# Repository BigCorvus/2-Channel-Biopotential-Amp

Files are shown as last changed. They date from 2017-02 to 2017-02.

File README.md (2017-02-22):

# 2-Channel-Biopotential-Amp
A small general purpose biopotential amplifier for ECG/EEG/EMG measurements based on the TI INA2321 dual instrumentation amplifier. The device can be connected to any ADC or microcontroller with built-in ADC.

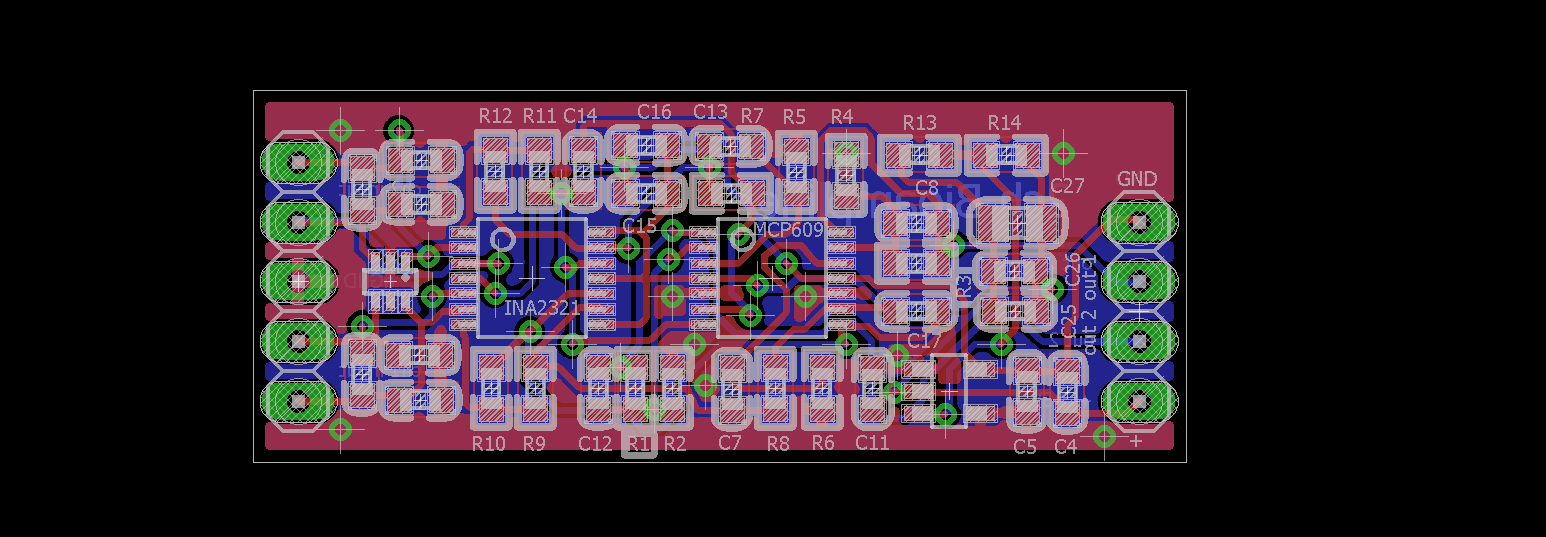
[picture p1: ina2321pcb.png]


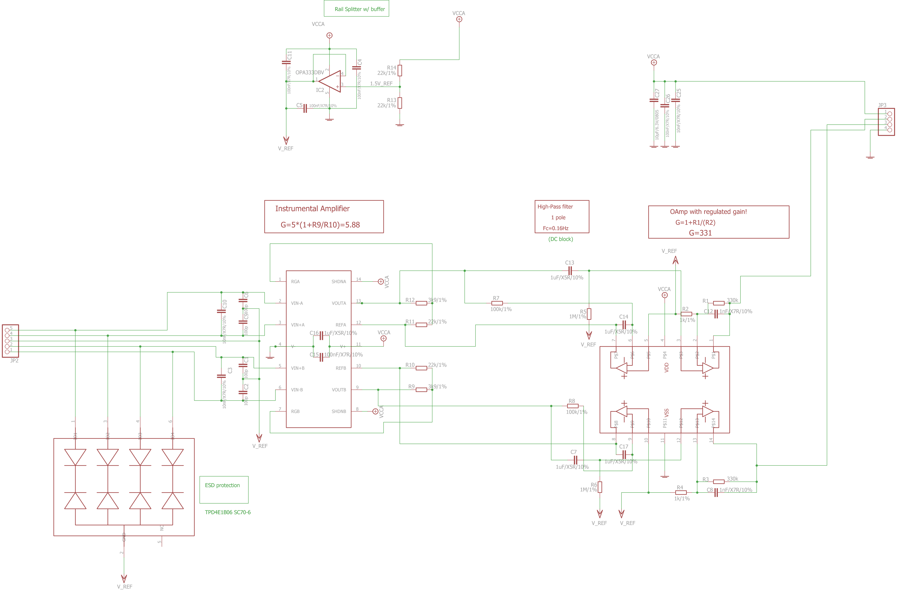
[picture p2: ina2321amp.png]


These can be stacked together to easily increase the channel count of your system.

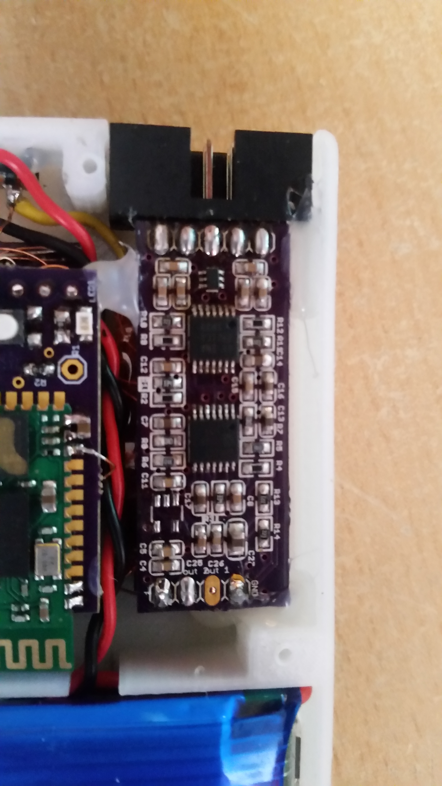
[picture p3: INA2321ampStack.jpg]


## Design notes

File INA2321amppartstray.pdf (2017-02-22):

INA2321 amp Parts Tray (passives)

Resistors – all 0603 1%:

1M: R5,6

100K: R7,8

3k9: R12,9

22k: R10,11,13,14

1k: R4,2

330k: R1,3

Caps:

4x 100p @ inputs

3x10n: @ inputs and C25

1µFx5r0603 C13,14,7,17

100n0603: C4,5,26,11,15

10µ0805: C27

1nF: C6,12

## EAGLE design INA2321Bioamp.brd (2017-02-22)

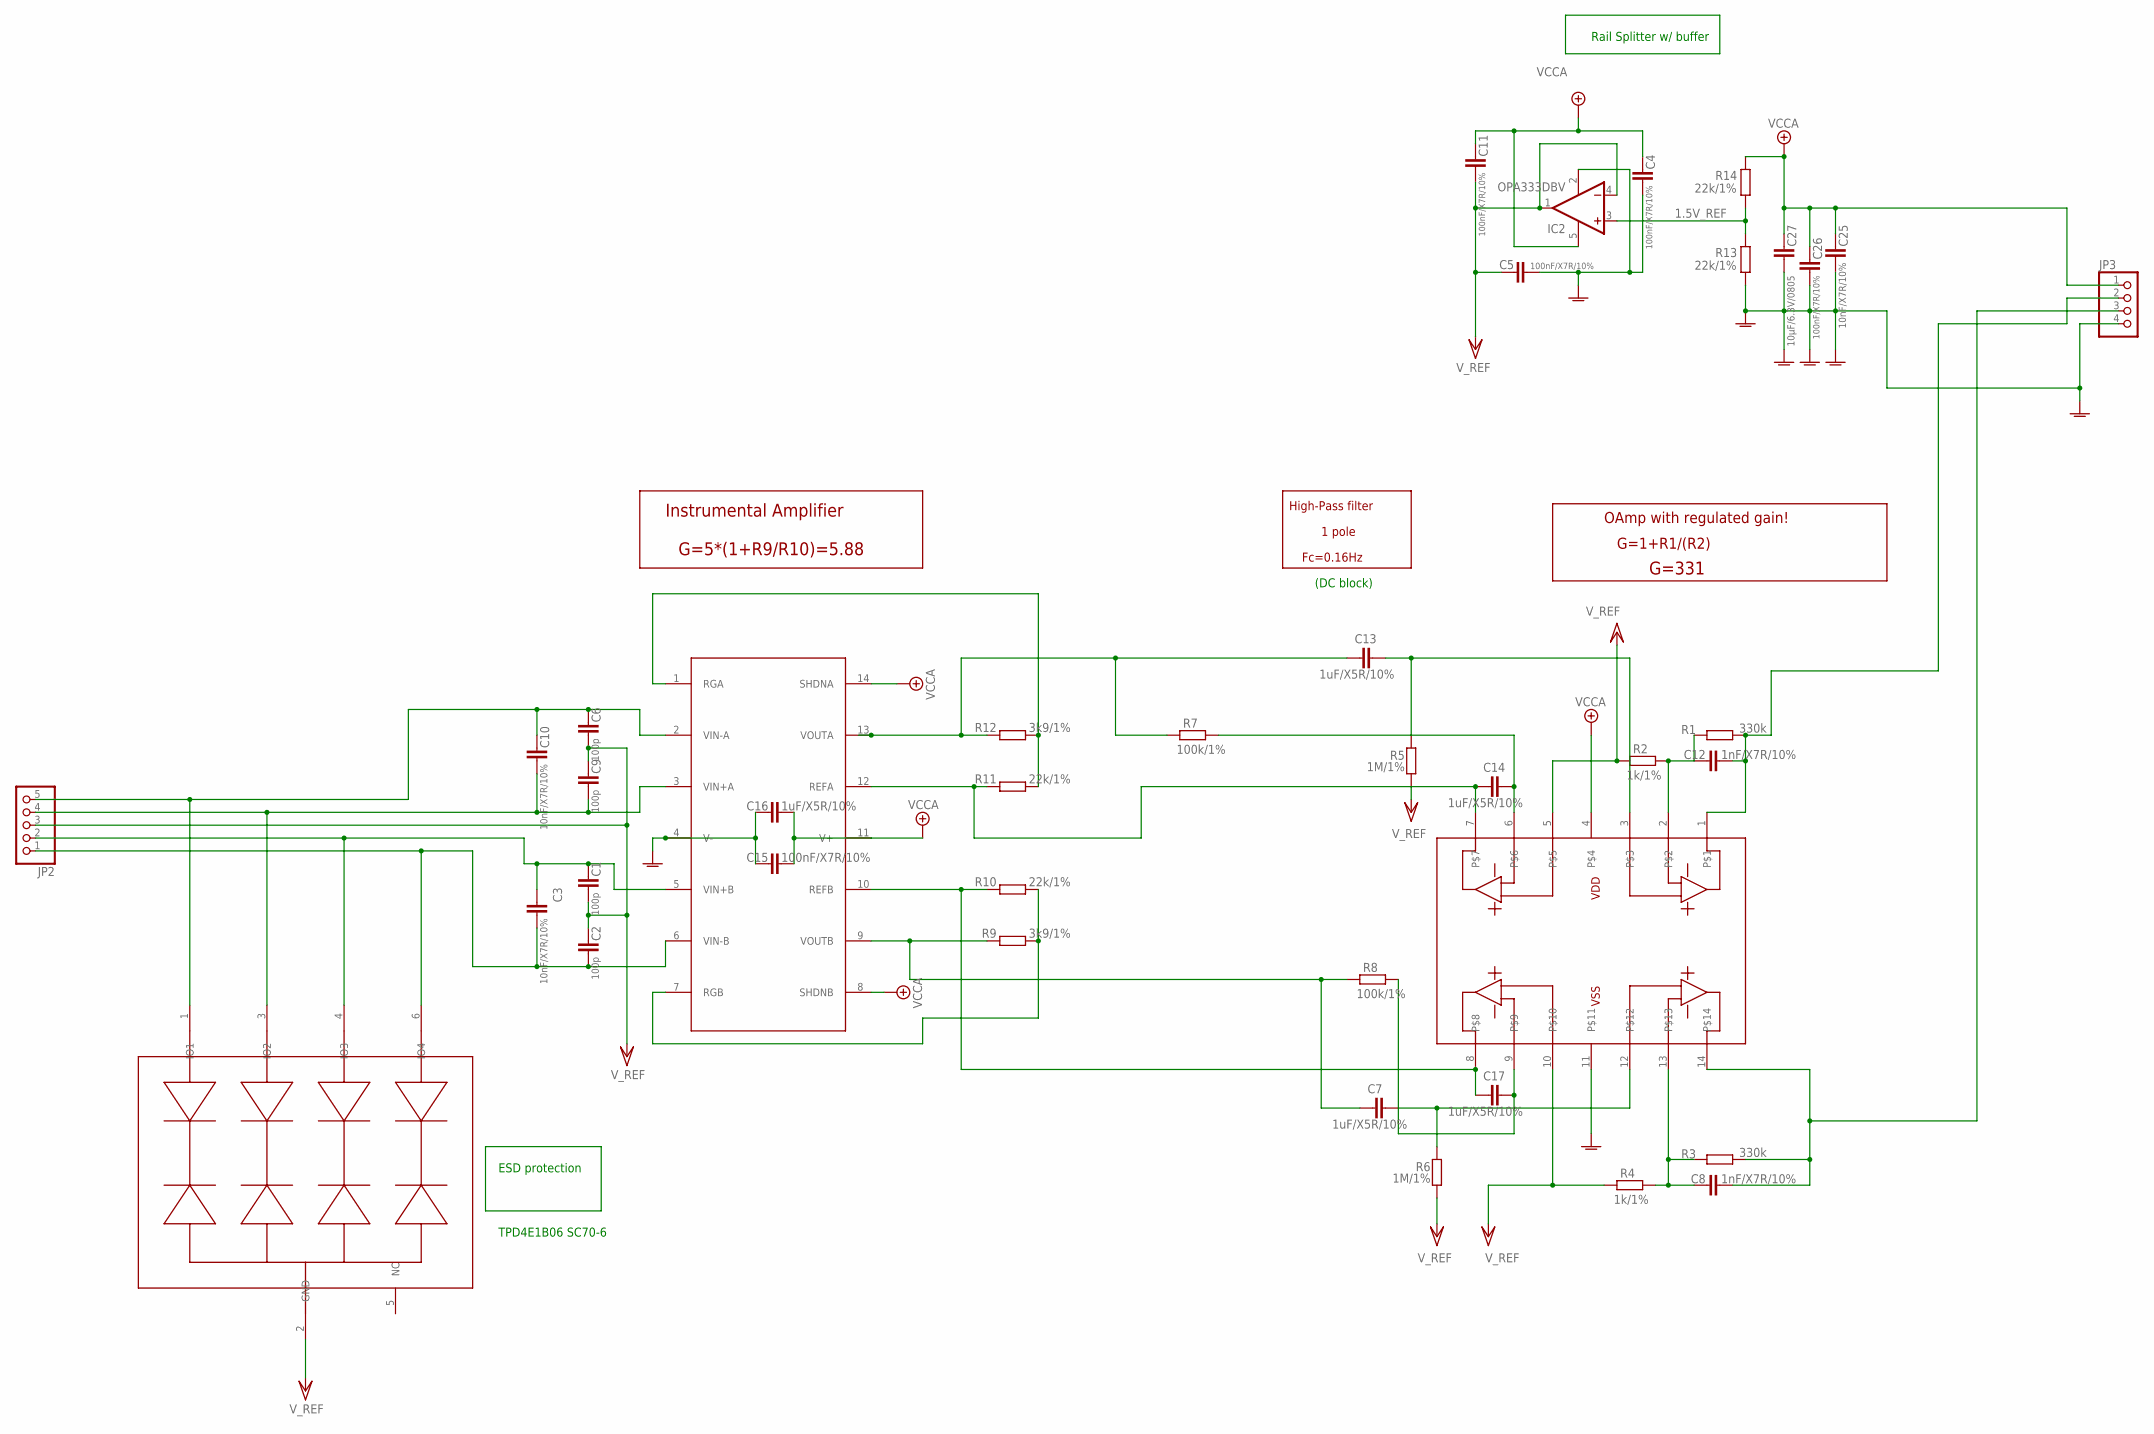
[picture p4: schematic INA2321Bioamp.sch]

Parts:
C1, C2, C6, C9: 100p; C0603_DWS
C3, C10, C25: 10nF/X7R/10%; C0603_DWS
C4, C5, C11, C15, C26: 100nF/X7R/10%; C0603_DWS
C7, C13, C14, C16, C17: 1uF/X5R/10%; C0603_DWS
C8, C12: 1nF/X7R/10%; C0603_DWS
C27: 10µF/6.3V/0805; C0805_5MIL_DWS
IC2: OPA333DBV; SOT23-5
JP2: PINHD-1X5; 1X05
JP3: PINHD-1X4; 1X04
R1, R3: 330k; R0603_5MIL_DWS
R2, R4: 1k/1%; R0603_5MIL_DWS
R5, R6: 1M/1%; R0603_5MIL_DWS
R7, R8: 100k/1%; R0603_5MIL_DWS
R9, R12: 3k9/1%; R0603_5MIL_DWS
R10, R11, R13, R14: 22k/1%; R0603_5MIL_DWS
U$1: INA2321; TSSOP14
U$2: TPD4E1B06; SC70-6L
U$3: MCP609; TSSOP14

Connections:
1.5V_REF: IC2.3 (+IN), R13.2, R14.1
+5V: C4.1, C11.1, C15.2, C16.2, C25.1, C26.1, C27.1, IC2.5 (V+), JP3.1, R14.2, U$1.8 (SHDNB), U$1.11 (V+), U$1.14 (SHDNA), U$3.4
GNDA: C4.2, C5.2, C15.1, C16.1, C25.2, C26.2, C27.2, IC2.2 (V-), JP3.4, R13.1, U$1.4 (V-), U$3.11
unnamed: C8.2, JP3.3, R3.2, U$3.14
unnamed: C6.1, C10.1, JP2.5, U$1.2 (VIN-A), U$2.1 (IO1)
unnamed: C13.1, R7.2, R12.2, U$1.13 (VOUTA)
unnamed: R11.1, R12.1, U$1.1 (RGA)
unnamed: C13.2, R5.1, U$3.3
unnamed: C12.1, R1.1, R2.1, U$3.2
unnamed: C12.2, JP3.2, R1.2, U$3.1
unnamed: C9.2, C10.2, JP2.4, U$1.3 (VIN+A), U$2.3 (IO2)
unnamed: R9.1, R10.1, U$1.7 (RGB)
unnamed: C1.1, C3.1, JP2.2, U$1.5 (VIN+B), U$2.4 (IO3)
unnamed: C2.2, C3.2, JP2.1, U$1.6 (VIN-B), U$2.6 (IO4)
unnamed: C14.2, R7.1, U$3.6
unnamed: C17.2, R8.1, U$3.9
unnamed: C17.1, R10.2, U$1.10 (REFB), U$3.8
unnamed: C14.1, R11.2, U$1.12 (REFA), U$3.7
unnamed: C7.2, R6.1, U$3.12
unnamed: C7.1, R8.2, R9.2, U$1.9 (VOUTB)
unnamed: C8.1, R3.1, R4.1, U$3.13
VCC/2: C1.2, C2.1, C5.1, C6.2, C9.1, C11.2, IC2.1 (OUT), IC2.4 (-IN), JP2.3, R2.2, R4.2, R5.2, R6.2, U$2.2 (GND), U$3.5, U$3.10

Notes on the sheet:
G=1+R1/(R2)
G=331
Fc=0.16Hz
High-Pass filter
OAmp with regulated gain!
1 pole
G=5*(1+R9/R10)=5.88
Instrumental Amplifier
(DC block)
Rail Splitter w/ buffer
TPD4E1B06 SC70-6
ESD protection

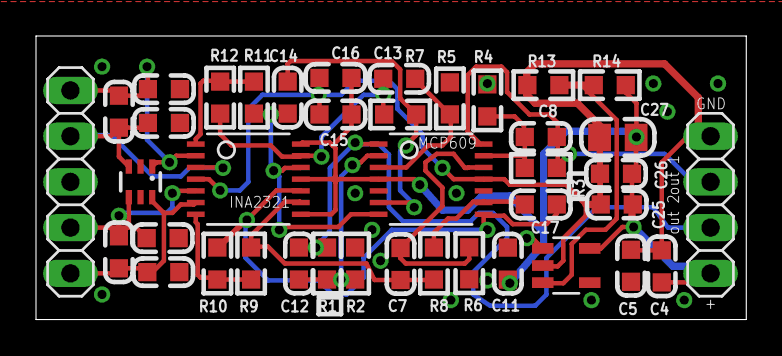
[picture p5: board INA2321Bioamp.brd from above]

Board: 2 copper layers, 39.5 x 15.8 mm, 40 parts (0 on the bottom side), 22 nets.
